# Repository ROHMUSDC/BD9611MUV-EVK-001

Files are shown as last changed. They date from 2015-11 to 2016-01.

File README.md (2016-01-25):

# BD9611MUV-EVK-001 Design Resource Repository
* Hardware Design Files and Documentation for the ROHM BD9611MUV-EVK-001 EVK

----
### Description: 
* The BD9611MUV is a high-resistance, wide voltage input (10V to 56V), synchronous step-down switching regulator.
* BD9611MUV offers design flexibility through user-programmable functions such as soft-start, operating frequency, high-side current limit, and  loop compensation.
* BD9611MUV uses voltage pulse width modulation, and drives 2 external N-channel FETs.
* The Under-Voltage Locked Output (EXUVLO) protection connected to its CTL terminal has high accuracy reference voltage.
* Its threshold voltage can be adjusted by the resistance ratio between VCC and GND as seen by pin CTL.
* BD9611MUV is safe for pre-biased outputs.  
* It  does not turn on the synchronous rectifier until the internal high-side FET has already started switching.

----
### Repository Contents
* Application Note Folder: Contains Draft Version of EVK Application Note
* Design Files: Contains Board, Gerber, Schematic, and BOM information for this EVK Board
* User Guide: Contains the User's Guide for this EVK

----
### Where to Purchase?
* http://www.rohm.com/web/global/distribution/-/dinventory/BD9611MUV-RE2/sample/0

----
### DISCLAIMER
This Technical Data is protected under copyright laws.

ROHM hereby grants you a nonexclusive, nontransferable license to use this Technical Data 
as long as you abide by the terms and conditions of this DISCLAIMER. 

However, you are not authorized to sell, loan, rent, lease, redistribute or license this Technical Data, 
in whole or in part, or in modified form, to anyone.

You may modify this Technical Data to suit your specific applications, 
but the rights to derivative works and said modifications shall belong to ROHM. 

You may make copies of this Technical Data as necessary for internal use only within your company.

In any case, the latest datasheet is considered the final design guideline and represents 
the only actual performance specifications.

ROHM shall not be responsible for ensuring proper application on all computer systems.
This Technical Data is provided AS IS. ROHM makes no guarantees, either implicitly or explicitly, 
regarding its usability, functionality, accuracy, merchantability, or fitness for a specific purpose.

In addition, you shall take full responsibility for the use of any information acquired from this Technical Data. 

ROHM does not assume warranty of any kind arising from the use of this Technical Data. ACCORDINGLY, 
IN NO EVENT SHALL ROHM BE RESPONSIBLE, WHETHER THROUGH CONTRACT OR TORT LIABILITY, 
FOR ANY DAMAGES (INCLUDING BUT NOT LIMITED TO LOST PROFITS OR OTHER INCIDENTAL, CONSEQUENTAL, 
OR PUNITIVE DAMAGES) ARISING OUT OF OR IN CONNECTION WITH THE USE OR APPLICATION OF THIS Technical Data.

Furthermore, this Technical Data is subject to change without notice.

Unless otherwise expressly provided herein, ROHM does not convey any license under patent rights 
or any other intellectual property rights (including those of third parties).

ROHM is not obligated to provide maintenance or support for the Technical Data.

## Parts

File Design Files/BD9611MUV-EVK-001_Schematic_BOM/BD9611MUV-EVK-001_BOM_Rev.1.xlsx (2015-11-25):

BD9611MUV-EVK-001 BOM Rev. 1 VIN=15V to 36V, VOUT=12V
Count | Reference Designator | Type | Value | Description | Manufacturer Part Number | Manufacturer | Configuration (mm)
1 | U1 | IC | - | - | BD9611MUV | ROHM | 3030
1 | R1 | Resistor | 1kΩ | 1/10W, 50V, 1% | MCR03ERTF1001 | ROHM | 1608
1 | R2 | Resistor | 15kΩ | 1/10W, 50V, 1% | MCR03ERTF1502 | ROHM | 1608
1 | R5 | Resistor | 27kΩ | 1/10W, 50V, 1% | MCR03EZPFX2702 | ROHM | 1608
1 | R7 | Resistor | 5.1kΩ | 1/10W, 50V, 1% | MCR03EZPF5101 | ROHM | 1608
1 | R8 | Resistor | 430Ω | 1/10W, 50V, 1% | MCR03ERTF4300 | ROHM | 1608
1 | RU1 | Resistor | 120kΩ | 1/10W, 50V, 1% | MCR03ERTF1203 | ROHM | 1608
2 | RU2, RCL | Resistor | 20kΩ | 1/10W, 50V, 1% | MCR03ERTF2002 | ROHM | 1608
1 | RD1 | Resistor | 10kΩ | 1/10W, 50V, 1% | MCR03ERTF1002 | ROHM | 1608
1 | RT | Resistor | 75kΩ | 1/10W, 50V, 1% | MCR03ERTF7502 | ROHM | 1608
1 | RHG | Resistor | 10Ω | 1/10W, 50V, 1% | MCR03ERTF10R0 | ROHM | 1608
1 | RS | Resistor | 5mΩ | 2W,1% | PMR100HZPFU5L00 | ROHM | 6432
1 | C1 | Ceramic Capacitor | 180pF | 50V, CH, 5% | GRM1885C1H181JA01D | MURATA | 1608
1 | C2 | Ceramic Capacitor | 2200pF | 50V, X7R, 10% | GRM188R71H333KA01D | MURATA | 1608
2 | CSS, CRTSS | Ceramic Capacitor | 10000pF | 16V, X7R, 10% | GRM188R71C103KA01D | MURATA | 1608
2 | CREG10 ,CVCC | Ceramic Capacitor | 1uF | 16V, X7R, 10% | GRM188R71C105KA01D | MURATA | 1608
1 | CBST | Ceramic Capacitor | 0.47uF | 25V, X7R, 10% | GRM188R71E474KA12D | MURATA | 1608
1 | CREG5 | Ceramic Capacitor | 0.1uF | 25V, X5R, 10% | GRM155R61E104KA87D | MURATA | 1005
4 | CIN | Ceramic Capacitor | 10uF | 50V, X7R, 10% | CL32B106BJNNNE | SAMSUNG | 3225
4 | COUT1 | Ceramic Capacitor | 10uF | 50V, X7R, 10% | CL32B106BJNNNE | SAMSUNG | 3225
1 | COUT2 | Aluminum Capacitor | 220uF | 50V, 20%, RADIAL | UVR1H221MPD1TD | NICHICON | φ10
2 | DI1, DI2 | Diode | SCHOTTKY | 20V, 1A | RB161VA-20TR | ROHM | 2513
2 | Tr1, Tr2 | Transistor | - | - | RSD221N06TL | ROHM | 6595
1 | L1 | Inductor | 7.7uH | ±20%,9.85mΩ(max),12.4A | CDEP147NP-7R7MC-95 | SUMIDA | 14.9×14.9
10 | R0, RD2, R6, RLG, RBST, RCLL, RCLH, J2, CSYNC, RVCC | Jumper | 0Ω | - | SOLDER JUMPER | - | 1608
1 | Pin(VIN) | Test Pin (RED) | - | - | LC-22-G-RED | VIN | φ10
2 | Pin(GND), Pin(PGND) | Test Pin (BLACK) | - | - | LC-22-G-BLACK | GND,PGND | φ10
1 | Pin(VOUT) | Test Pin (YELLOW) | - | - | LC-22-G-YELLOW | VOUT | φ10

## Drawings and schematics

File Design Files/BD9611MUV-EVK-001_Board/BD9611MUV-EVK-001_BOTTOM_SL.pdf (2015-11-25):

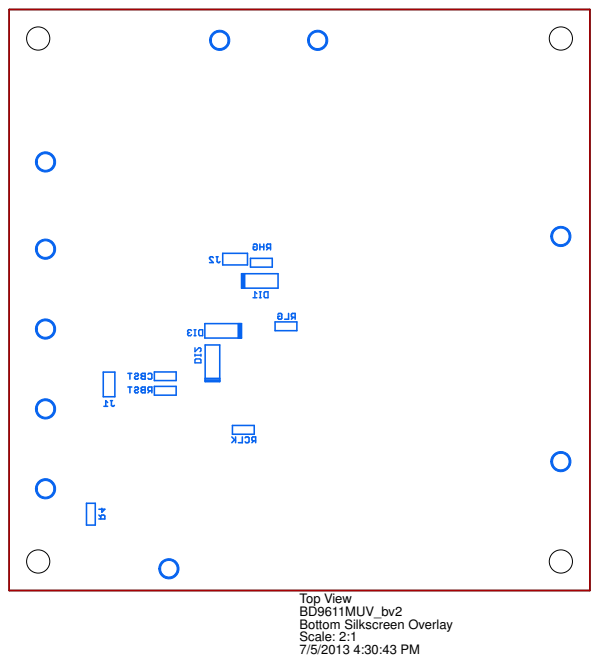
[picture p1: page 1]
Bottom Silkscreen Overlay; Top View BD9611MUV_bv2; Scale: 2:1 7/5/2013 4:30:43 PM

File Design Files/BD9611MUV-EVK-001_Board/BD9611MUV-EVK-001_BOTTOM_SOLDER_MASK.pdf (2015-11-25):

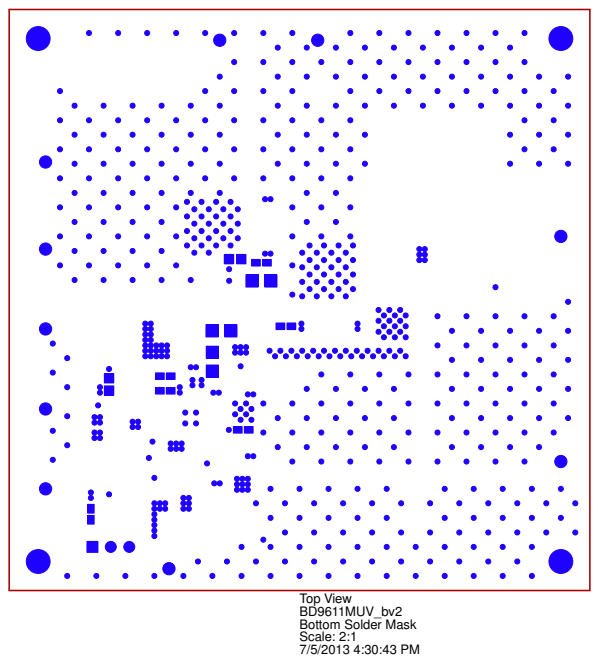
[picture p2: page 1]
Bottom Solder Mask; Top View BD9611MUV_bv2; Scale: 2:1 7/5/2013 4:30:43 PM

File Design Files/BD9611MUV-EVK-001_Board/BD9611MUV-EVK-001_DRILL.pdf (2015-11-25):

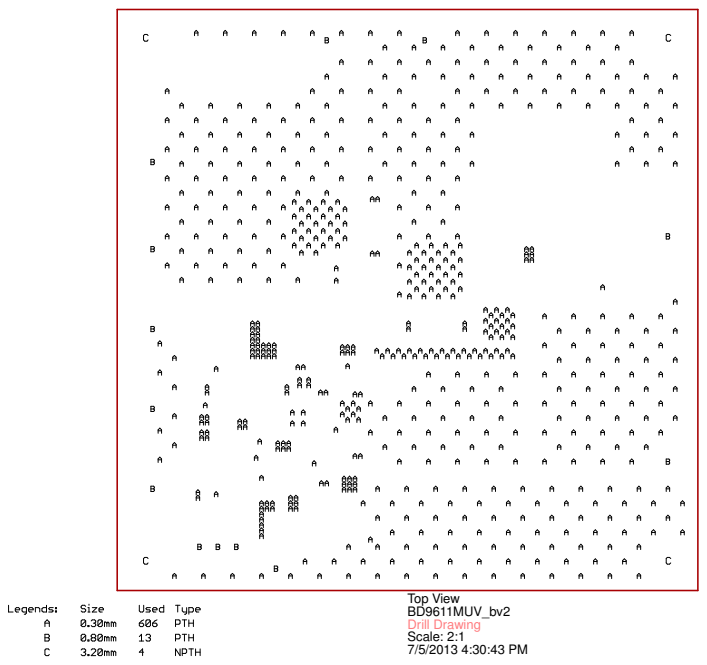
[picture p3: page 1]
Drill Drawing; Top View BD9611MUV_bv2; Scale: 2:1 7/5/2013 4:30:43 PM

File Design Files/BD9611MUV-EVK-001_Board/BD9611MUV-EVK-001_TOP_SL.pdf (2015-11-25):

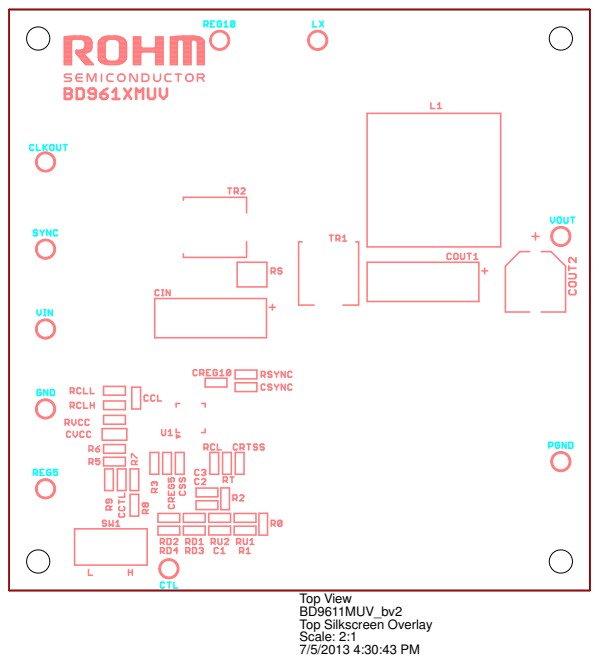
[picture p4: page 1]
Top Silkscreen Overlay; Top View BD9611MUV_bv2; Scale: 2:1 7/5/2013 4:30:43 PM

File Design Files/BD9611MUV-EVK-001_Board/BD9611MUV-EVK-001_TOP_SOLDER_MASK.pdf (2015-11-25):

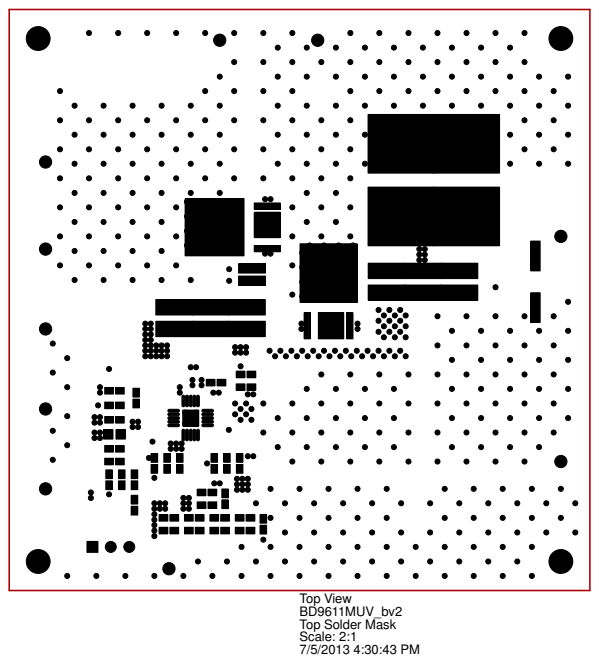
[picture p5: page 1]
Top Solder Mask; Top View BD9611MUV_bv2; Scale: 2:1 7/5/2013 4:30:43 PM

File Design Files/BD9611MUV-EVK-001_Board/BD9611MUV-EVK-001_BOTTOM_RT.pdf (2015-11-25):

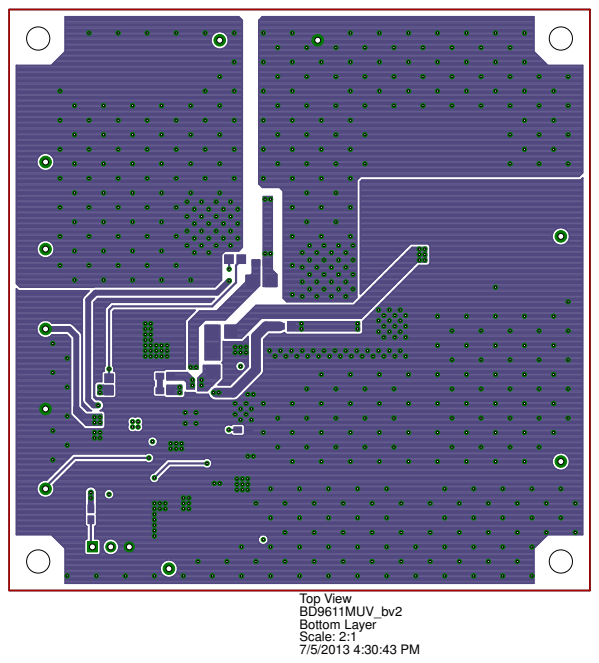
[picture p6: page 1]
Bottom Layer; Top View BD9611MUV_bv2; Scale: 2:1 7/5/2013 4:30:43 PM

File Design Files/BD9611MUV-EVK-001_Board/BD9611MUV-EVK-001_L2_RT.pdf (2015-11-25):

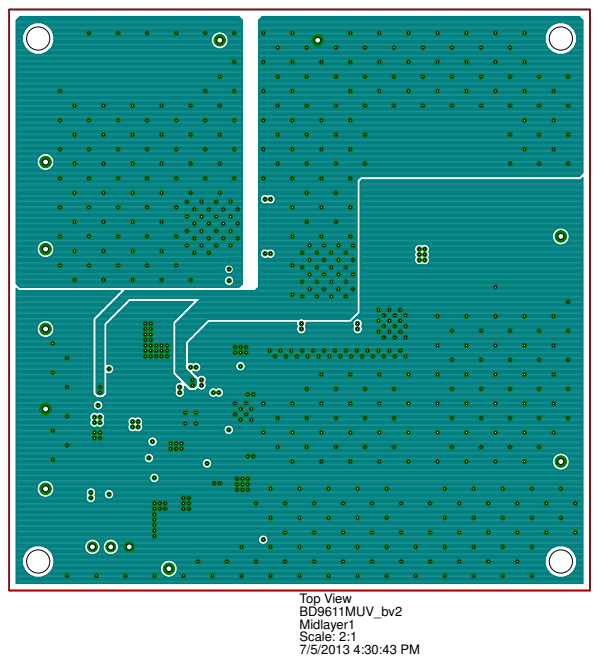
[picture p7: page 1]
Midlayer1; Top View BD9611MUV_bv2; Scale: 2:1 7/5/2013 4:30:43 PM

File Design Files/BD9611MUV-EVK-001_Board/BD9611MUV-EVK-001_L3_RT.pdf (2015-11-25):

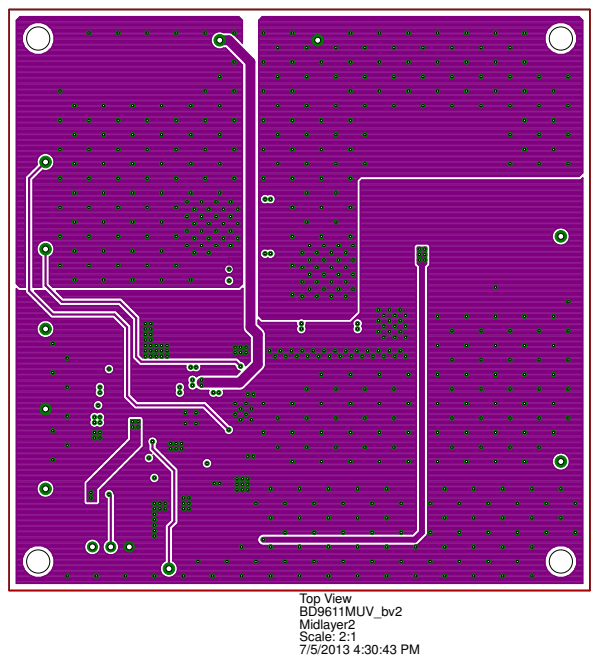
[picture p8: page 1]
Midlayer2; Top View BD9611MUV_bv2; Scale: 2:1 7/5/2013 4:30:43 PM

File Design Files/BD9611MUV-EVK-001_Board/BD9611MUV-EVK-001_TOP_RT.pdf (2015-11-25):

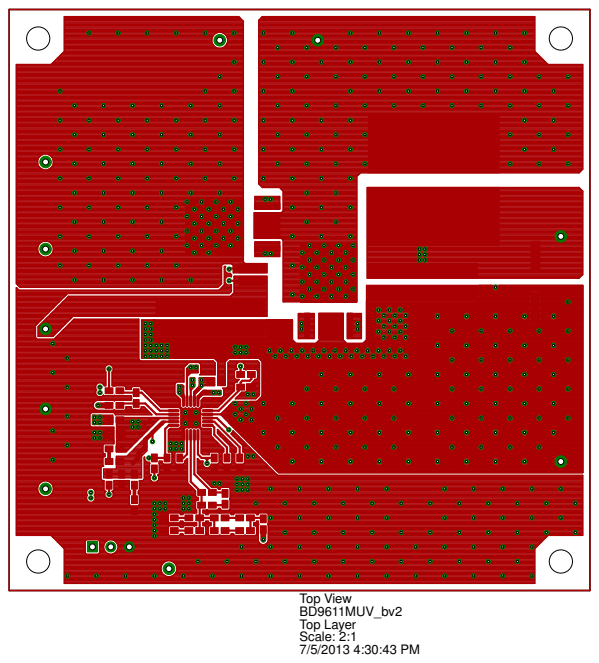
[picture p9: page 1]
Top Layer; Top View BD9611MUV_bv2; Scale: 2:1 7/5/2013 4:30:43 PM

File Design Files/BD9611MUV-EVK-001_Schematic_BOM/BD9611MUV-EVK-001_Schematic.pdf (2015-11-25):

A

A

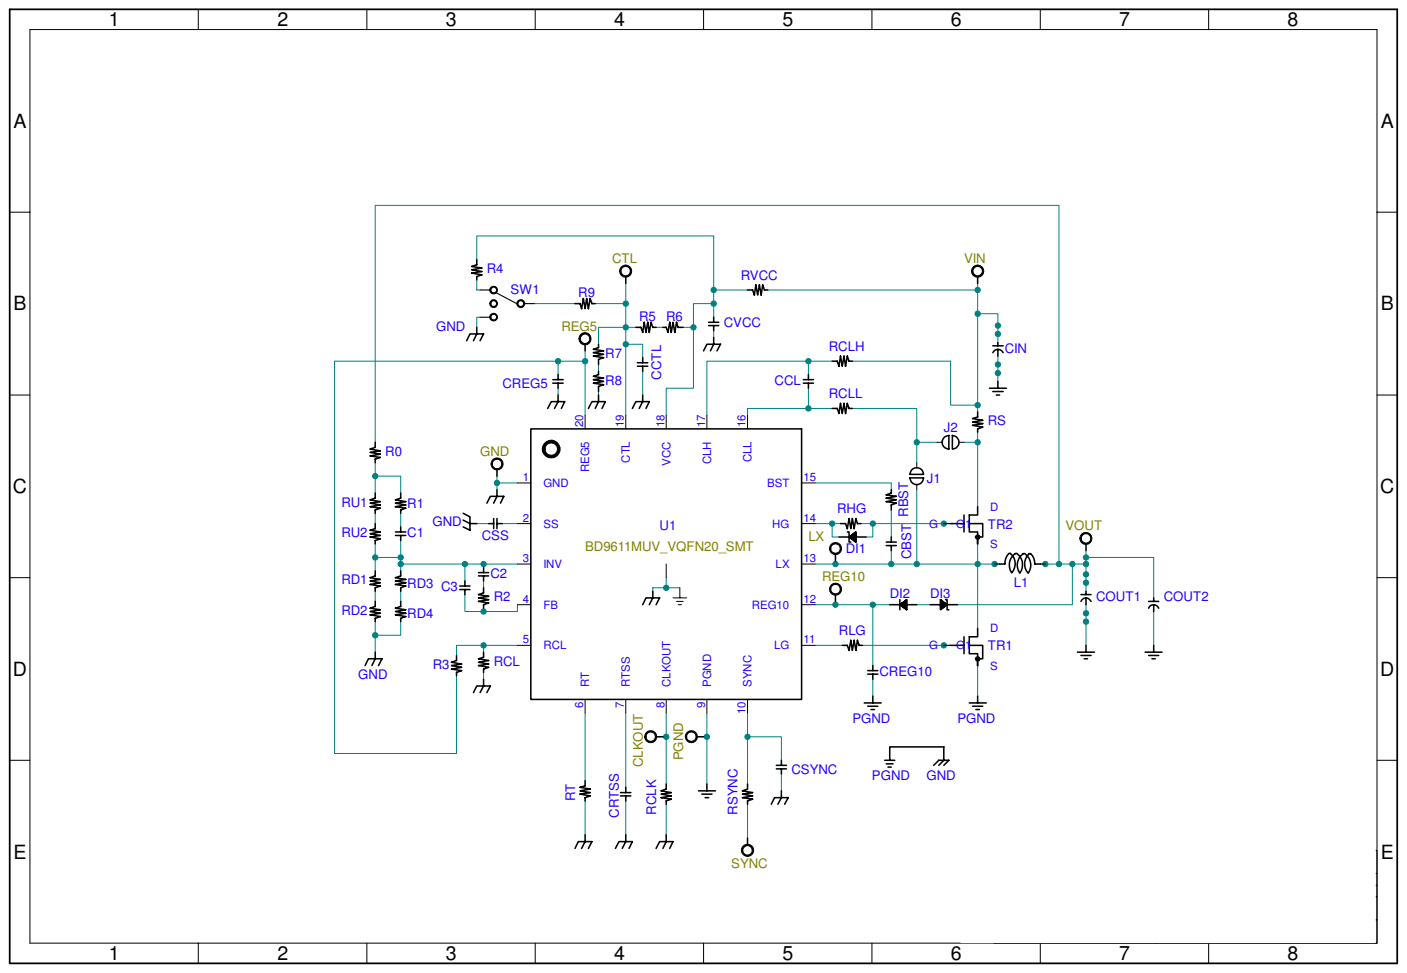
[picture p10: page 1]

Job Order: 13-43879 | Requester: Mr. Takafumi Morinaka

Date: 7/4/2013 11:00:05 AM | Drawn by: John Jasmin Burgos
